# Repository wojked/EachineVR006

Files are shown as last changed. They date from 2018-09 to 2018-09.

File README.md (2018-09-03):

# Eachine VR006 Screen Conversion (fork with some screws)
forked from: https://github.com/nomand/EachineVR006



This project offers 3D printing files and instructions to re-house the screen and electrical components extracted from a cheap FPV headset [Eachine VR006](https://www.banggood.com/Eachine-E013-VR006-VR-006-One-antenna-3-Inch-5_8G-40CH-Mini-FPV-Goggles-Build-in-3_7V-500mAh-Battery-p-1239625.html) to use as a stand-alone spectator screen for Drone Racing and other RF hobby applications.

The original video version of this guide is available [here](https://youtu.be/1_T4DhQ6De4).

This version offers a slightly different housing with screws instead of sliding. 
Additionally there is no need to re-solder antyhing.

# License

You do not have permission to re-post, embed or host any content of this guide anywhere without written permission.
You are allowed to link to this guide using either [00.jpg](/Images/00.jpg) or [000.jpg](/Images/000.jpg).
Follow this guide at your own risk, and observe lipo safety.

# Guide

### Step 1

Remove the SMA cover and the retaining brass nut.



### Step 2

Underneath, unscrew 4 phillips screws and lift the top half of the plastic body.



### Step 3

The battery is held in place with a piece of foam and double sticky tape. Remove the foam and carefully cut along the tape with a craft knife to avoid prying the lipo battery.
Remove the control board and the fresnel lens. The screen assembly should freely slide out of the housing.



### Step 4

Be careful removing the screen, as it's not attached to the circuit board. Pull them gently together to avoid damaging the ribbon cable.



There are two variants of this board - the "diversity" version with two antennas (not real RX diversity) and the single antenna version I have here, my case design is for this version.



### Step 5

Next, you'll tape up the exposed breakout pins to avoid short circuiting them when you secure the screen to the surface (the back of the LCD is metal).



Cut some pieces of electrical tape to cover the breakout pins and gently press the screen onto the board to secure it with double sticky tape.
Use double sided tape, foam tape will make the assembly too thick.



### Step 6

Navigate to [/STL/](/STL/), download and 3D print the housing.





I created this to fit on a 10x10 printing platform, which is common among lowest-end printers. Due to this, the USB charging port sticks out a bit. If you want to make it flush with the side of the case, simply extrude the right wall by 3mm to the left.

### Step 7

Remove the metal frame from the LCD panel. It will only get caught in the ridges of the 3D print and may actually damage your screen.
Note that not all of the version have this frame.



### Step 8

Slot the assembly into the body of the case, ribbon cable side first, carefully allowing the case to bend it over the edge.



### Step 9 (not needed here)

In the original version, some re-soldering was needed. Please skip this step.

### Step 10

Add some foam padding to the motherboard to sit against the control board to prevent it from sinking into the case when pressing the buttons.
Place the buttons from the VR006 into the slots in the back part of the housing.



### Step 11

Put the two 3D-printed parts together, place 4 M4 screws into the slots.



### Done!

Your screen assembly is now complete! Happy flying!



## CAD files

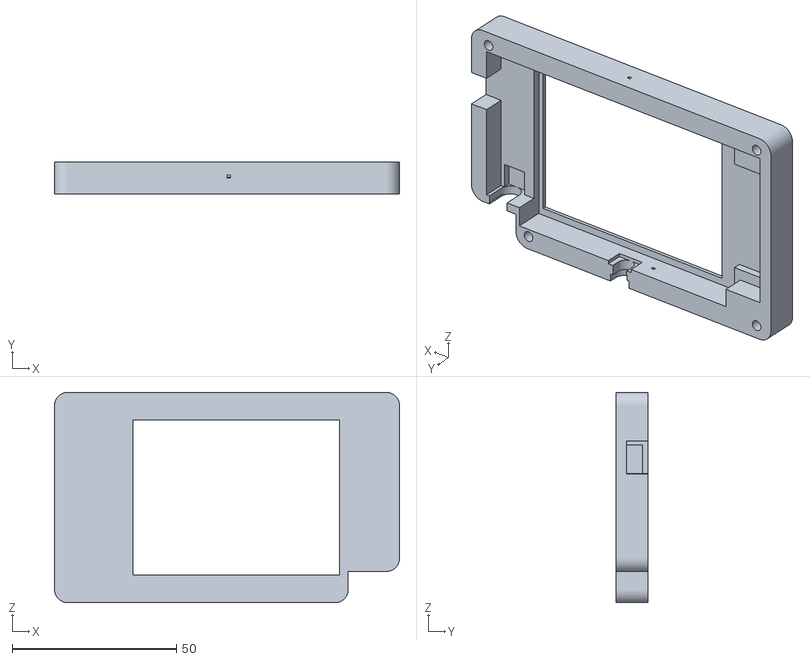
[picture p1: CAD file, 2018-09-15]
STL/forked-vr006-rounded-front.stl
105.0 x 9.72 x 64.0

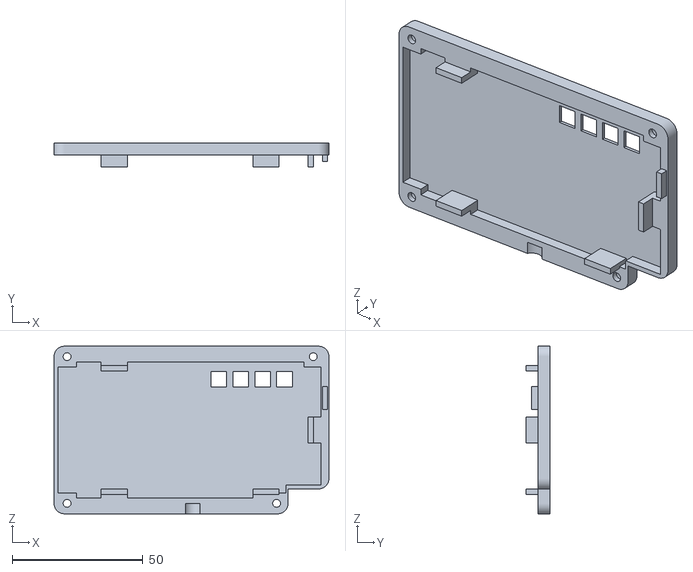
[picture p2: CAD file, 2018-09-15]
STL/forked-vr006-rounded-back.stl
105.0 x 9.00 x 64.0

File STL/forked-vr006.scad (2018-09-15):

CUBE_WIDTH_BIGGER = 100;
CUBE_WIDTH_SMALLER = 20;

CUBE_WIDTH = 2;
CUBE_DEPTH= 30;
CUBE_HEIGHT = 70;

X_BIGGER_OFFSET = 11;
X_OFFSET = -40;
X_SMALLER_OFFSET = -51;

/* [CORNERS] */
CORNER_DIAMETER = 8;

/* [BUTTONS] */
BUTTON_SIZE = 6.00; //5.80
BUTTON_TOTAL_WIDTH = 31.10;
BUTTON_DISTANCE = (BUTTON_TOTAL_WIDTH - 4*BUTTON_SIZE) / 3 + BUTTON_SIZE;

/* [MOUNTING ELEMS] */
SCREW_DIAMETER = 3; // M3 screw
SCREW_HEAD_DIAMETER = 6.4; // M3 screw
SCREW_HEAD_THICKNESS = 3.07; // M3 screw
SCREW_X_OFFSET = 46;
SCREW_Z_OFFSET = 28.0; //27.8

/* EXTRA_SIZE */
WIDER_BY = 2;
EXTRA_DEPTH = 3.5;

EXPLODE = 0;

/* [HIDDEN] */
$fn = 128;


//back_united();
//translate([0,-16.5,0])
front_united();

module back_united(){
    union(){
        back_bigger_part();
        translate([-EXPLODE, 0 ,0])
        back_middle_part();
        translate([-WIDER_BY, 0 ,0])
        back_middle_part();
        translate([-WIDER_BY-2*EXPLODE, 0 ,0])
        back_smaller_part();
    }    
}

module front_united(){
    difference(){
        union(){
            front_bigger_part();
            translate([-EXPLODE, 0 ,0])
            front_middle_part();
            translate([-WIDER_BY, 0 ,0])
            front_middle_part();
            translate([-WIDER_BY-2*EXPLODE, 0 ,0])
            front_smaller_part();
        };        

        
        
        // Front smoothing
        color("green")
        translate([0,-1.72,0])
        cube([120,4,80], true);                    
        
        // Back smoothing
        color("green")
        translate([0,12,0])
        cube([120,4,80], true);               
    }    
}

module screw_slot(height) {
    cube_ratio = 1.5;
//    difference(){
//        cube([cube_ratio*diameter,cube_ratio*diameter, height], true);              
//        cylinder(height*2,SCREW_DIAMETER/2, SCREW_DIAMETER/2, true);  
//    }  
    cylinder(height,SCREW_DIAMETER/2, SCREW_DIAMETER/2, true);      
}

module screw_head(height) {;
    cylinder(height,SCREW_HEAD_DIAMETER/2, SCREW_HEAD_DIAMETER/2, true);      
}

module extra_border(){
    bottom_up_thickness = 5;
    bottom_border_width = 98.5;
    upper_border_width = 85.5;
    
    antenna_side_width = 2;
    antenna_side_height = 52;    
    
    color("red")
    translate([-upper_border_width/2-6.5,-EXTRA_DEPTH,-30.5])
    cube([upper_border_width,2+EXTRA_DEPTH,bottom_up_thickness]);
    
    color("pink")
    translate([-bottom_border_width/2,-EXTRA_DEPTH,26])
    cube([bottom_border_width,2+EXTRA_DEPTH,bottom_up_thickness]);    
    
    color("green")
    translate([46,-EXTRA_DEPTH, -antenna_side_height/2+1.8])
    cube([3.2,2+EXTRA_DEPTH,antenna_side_height]);    
    
    color("violet")
    translate([36,-EXTRA_DEPTH,-24.2])
    cube([13,2+EXTRA_DEPTH,antenna_side_width]);    
    
    color("grey")
    translate([34.3,-EXTRA_DEPTH, -28.2])
    cube([2,2+EXTRA_DEPTH,6]);     
 
    color("orange")
    translate([-49.3,-EXTRA_DEPTH, -antenna_side_height/2])
    cube([3.2,2+EXTRA_DEPTH,antenna_side_height]);     
}

module extra_border_rounded_base_side(){
    height = 1;
    x_offset = 51 - CORNER_DIAMETER/2;
    z_offset = 32 - CORNER_DIAMETER/2; 
    antenna_limiter = 14.6;    
    antenna_limiter_z = 9.5;
    
    color("pink")
    hull(){
        translate([x_offset-antenna_limiter,0,-(z_offset-antenna_limiter_z)])
        rotate([90,0,0])
        cylinder(height,CORNER_DIAMETER/2, CORNER_DIAMETER/2, true);

        translate([x_offset+1,0,-(z_offset-antenna_limiter_z)])
        rotate([90,0,0])
        cylinder(height,CORNER_DIAMETER/2, CORNER_DIAMETER/2, true);        
        
        translate([x_offset+1,0,z_offset])
        rotate([90,0,0])
        cylinder(height,CORNER_DIAMETER/2, CORNER_DIAMETER/2, true);   

        translate([x_offset-antenna_limiter,0,z_offset])
        rotate([90,0,0])
        cylinder(height,CORNER_DIAMETER/2, CORNER_DIAMETER/2, true);            
    }    
    
}

module extra_border_rounded_base(){
    height = 1;
    x_offset = 51 - CORNER_DIAMETER/2;
    z_offset = 32 - CORNER_DIAMETER/2;
    antenna_limiter = 14.6;
    
    color("red")
    hull(){
        translate([-x_offset,0,-z_offset])
        rotate([90,0,0])
        cylinder(height,CORNER_DIAMETER/2, CORNER_DIAMETER/2, true);          
        
        translate([-x_offset,0,z_offset])
        rotate([90,0,0])
        cylinder(height,CORNER_DIAMETER/2, CORNER_DIAMETER/2, true);       
    
        translate([x_offset-antenna_limiter,0,-z_offset])
        rotate([90,0,0])
        cylinder(height,CORNER_DIAMETER/2, CORNER_DIAMETER/2, true);          
        
        translate([x_offset-antenna_limiter,0,z_offset])
        rotate([90,0,0])
        cylinder(height,CORNER_DIAMETER/2, CORNER_DIAMETER/2, true);         
    }
}

module extra_border_rounded(){
    //This is the new base shape
    height = 1;    
    
    union(){
        extra_border_rounded_base();
        extra_border_rounded_base_side();        
    }            
}

module extra_border_rounded_empty_inside(thickness){
    // This is the new rim
    
    base_height = 1;
    
    scale([1,thickness,1])
    difference(){
        extra_border_rounded();     

        translate([-6.5,0,0])    
        cube([84.5,base_height*2,52], true);     
        
        translate([40,0,2])       
        cube([18,base_height*2,48], true); //53 Z              
    } 
}

module extra_stablisers(){
    thickness = 5 + EXTRA_DEPTH;
    lower_thickness = 4;
    z_offset = 23.6;
    
    smaller_thickness = 3 + EXTRA_DEPTH;

    color("green")
    translate([-30,-lower_thickness/2,z_offset+2])
    cube([10,lower_thickness,2], true); 
    color("violet")
    translate([-30,-thickness/2,z_offset])
    cube([10,thickness,2], true); 
     
     
    color("green")
    translate([-30,-lower_thickness/2,-z_offset-2])
    cube([10,lower_thickness,2], true);         
    color("green")
    translate([-30,-thickness/2,-z_offset])
    cube([10,thickness,2], true);
    
    color("green")
    translate([26,-lower_thickness/2,-z_offset-2])
    cube([6,lower_thickness,2], true);      
    color("green")
    translate([28,-thickness/2,-z_offset])
    cube([10,thickness,2], true);      
    
    
    color("green")
    translate([47,-lower_thickness/2,0])
    cube([4,lower_thickness,10], true);          
    color("green")
    translate([45,-thickness/2,0])
    cube([2,thickness,10], true);     
    
    color("purple")
    translate([50.5,-smaller_thickness/2,12.3])
    cube([2,smaller_thickness,8.8], true);   

    //Edge
    color("green")
    translate([42.5,-lower_thickness/2,-21.5])
    cube([14,lower_thickness,1], true);    
    
    //Edge screw
    color("red")
    translate([46.5,-lower_thickness/2,25])
    cube([8,lower_thickness,2], true);     
   
    //Edge screw
    color("green")
    translate([32.0,-lower_thickness/2,-25])
    cube([8,lower_thickness,2], true);      
       
    
    //Edge screw
    color("green")
    translate([-46.5,-lower_thickness/2,25])
    cube([8,lower_thickness,2], true);          
    
    //Edge screw
    color("green")
    translate([-46.5,-lower_thickness/2,-25])
    cube([8,lower_thickness,2], true);         
}

module larger_button(){
    cube([BUTTON_SIZE, BUTTON_SIZE, 4], true);
}

module larger_button_slots(){
    buttons = 4;
    initial_offset = (buttons-1)*BUTTON_DISTANCE;
    
    translate([-initial_offset/2,0,0])    
    union(){            
        for(n=[0:1:buttons-1]){
            translate([n*BUTTON_DISTANCE,0,0])
            larger_button();
        }
    }
}

module back_body_base(){
    union(){
        rotate([180,0,0])
        difference(){
            rotate([180,0,0])            
            extra_border_rounded();            
            
            translate([22.5, -1, -19.4])
            rotate([90,0,0])        
            larger_button_slots();            
        }        
       
        extra_stablisers();
    }
}

module screw_slots(){
    screw_depth = 20;
    slot_diameter = SCREW_DIAMETER/2 + 1.0;      
    y_offset = 6;    

    color("red")
    translate([-SCREW_X_OFFSET,y_offset,SCREW_Z_OFFSET])
    rotate([90,0,0])
    screw_slot(screw_depth);     

    color("red")
    translate([-SCREW_X_OFFSET,y_offset,-SCREW_Z_OFFSET])
    rotate([90,0,0])
    screw_slot(screw_depth);           
    
    color("red")
    translate([SCREW_X_OFFSET,y_offset,SCREW_Z_OFFSET])
    rotate([90,0,0])
    screw_slot(screw_depth);           
    
    color("red")
    translate([SCREW_X_OFFSET-14,y_offset,-SCREW_Z_OFFSET])
    rotate([90,0,0])
    screw_slot(screw_depth);        
}

module screw_heads(){
    screw_depth = 3;
    slot_diameter = SCREW_HEAD_DIAMETER/2 + 1.0;      
    y_offset = 6;    

    union(){      
        color("red")
        translate([-SCREW_X_OFFSET,y_offset,SCREW_Z_OFFSET])
        rotate([90,0,0])
        screw_head(screw_depth);
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

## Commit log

2018-09-03 Wider with screws (#1)
    * Modified the readme, added a very early PoC of the wider version.
    * Some progress. Still code is not clean.
    * Wider with place for screw heads.
    * Moved the screws
    * Modified the screw slots on the front (added an offset to prevent negative on front)
    [forked-vr006-rounded-back.stl, forked-vr006-rounded-front.stl, forked-vr006.scad]
2018-09-11 Main screen slot is wider now as in original.
    [forked-vr006.scad]
2018-09-11 Front smoothing.
    [forked-vr006.scad]
2018-09-11 Antenna has thinner plastic now for more threading.
    [forked-vr006.scad]
2018-09-11 Ribbon slot is wider now for some loose.
    [forked-vr006.scad]
2018-09-11 Restored cut out.
    [forked-vr006.scad]
2018-09-11 Added back smoothing too.
    [forked-vr006.scad]
2018-09-11 Weird geometry fix.
    [forked-vr006-rounded-front.stl, forked-vr006.scad]
2018-09-15 Back updated to match the front.
    [forked-vr006-rounded-back.stl]
2018-09-15 Back has now larger outiside slot for minijack.
    [forked-vr006-rounded-back.stl, forked-vr006.scad]
2018-09-15 Minor corrections.
    [forked-vr006-rounded-back.stl, forked-vr006.scad]
2018-09-15 Front with larger outside minijack slot
    [forked-vr006-rounded-front.stl, forked-vr006.scad]
2018-09-15 Front geometry fix.
    [forked-vr006-rounded-front.stl, forked-vr006.scad]
